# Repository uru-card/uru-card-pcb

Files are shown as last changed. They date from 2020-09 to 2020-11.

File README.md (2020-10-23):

# URU Card PCB

[URU Card](https://github.com/uru-card/uru-card) is an Arduino based FIDO2 Authenticator. This repository contains Eagle CAD design files to build the device.

## Schematic

The schematic for the URU Card is presented on the figure below:

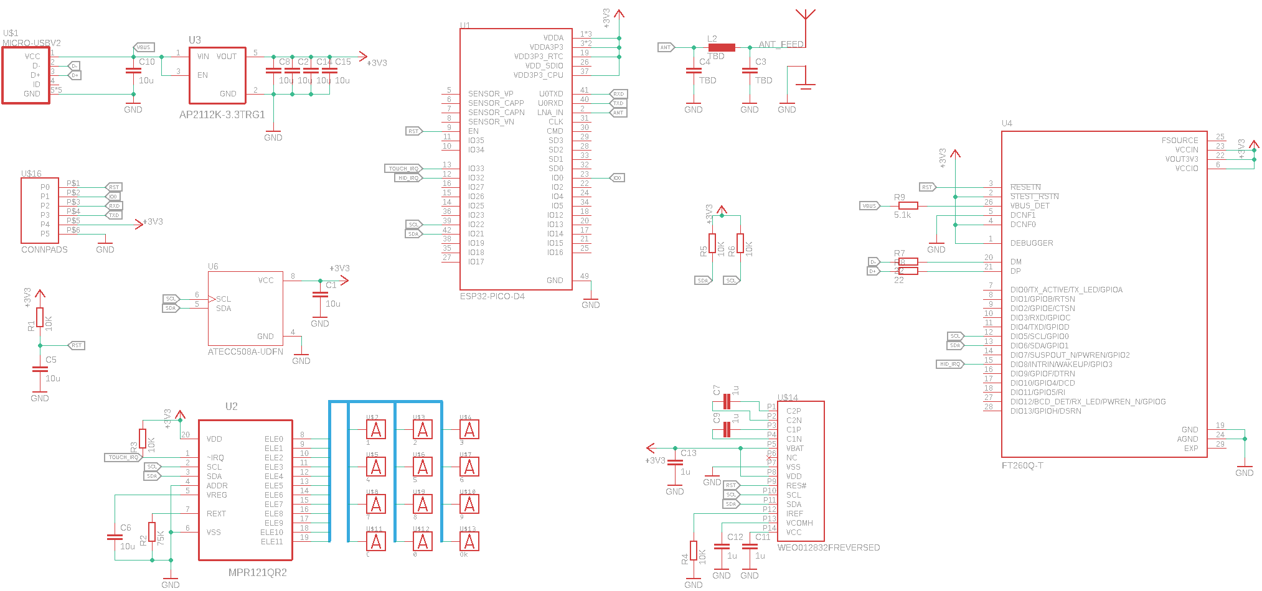
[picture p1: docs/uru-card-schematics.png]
URU Card schematic


Components requried to build the device

* ESP32 Pico D4 microcontroller
* ATECC508A or ATECC608A
* MPR121 touch keyboard controller
* SSD1306 based OLED display
* AP2112 voltage regulator
* MicroUSB socket
* A bunch of 0603 resistors and capacitors

## Mainboard PCB

The components are mounted on the mainboard. In fact it's the only PCB required to build the device.

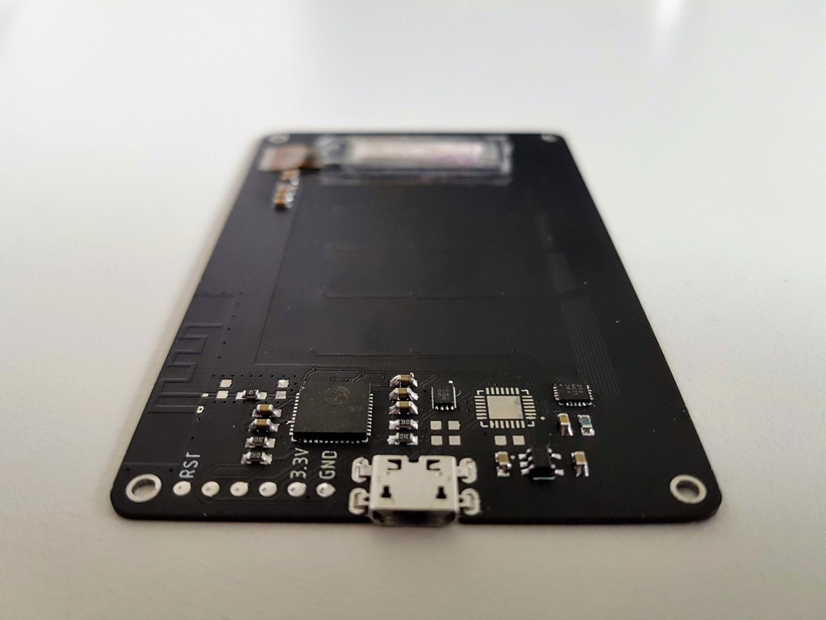
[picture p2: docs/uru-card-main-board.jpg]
URU Card mainboard


## Authors

* [**Andrey Ovcharov**](https://github.com/snakeye) - project owner

See also the list of [contributors](https://github.com/uru-card/uru-card/contributors) who participated in this project.

## References

* [Information about URU Card project](https://en.ovcharov.me/category/fido2/)

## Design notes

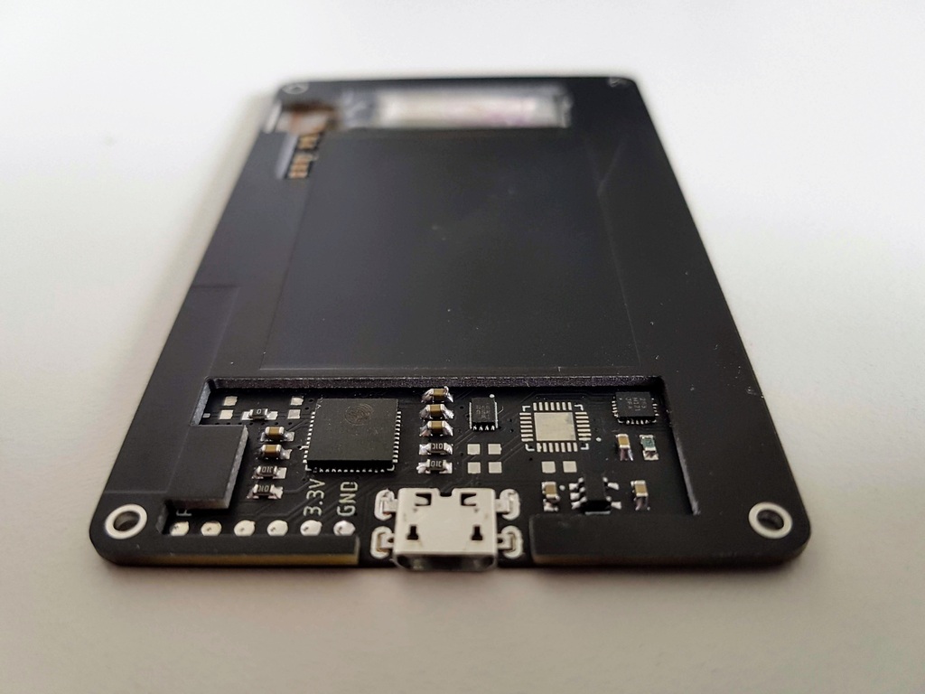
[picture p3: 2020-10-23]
docs/uru-card-spacer-board.jpg

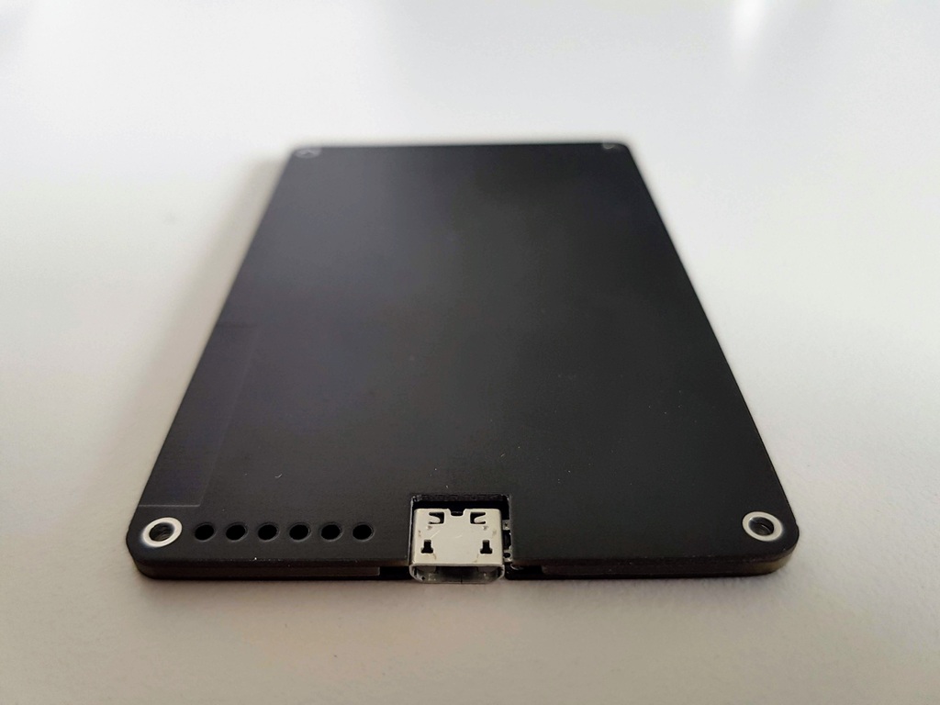
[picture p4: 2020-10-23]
docs/uru-card-cover-board.jpg

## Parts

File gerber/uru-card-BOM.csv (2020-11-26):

Comment | Designator | Footprint | LCSC Part # | Qty | Value | Device | Package | Parts | Description | AVAILABILITY | DESCRIPTION | MF | MP | PACKAGE | POPULARITY | PRICE | SPICEPREFIX
10K | R1, R3, R4, R5, R6 | R0603 | C25804 | 5 |  | R-EU_R0603 |  |  | RESISTOR, European symbol |  |  |  |  |  | 70 |  | R
10u | C1, C2, C5, C6, C8, C10, C14, C15 | C0603 | C19702 | 8 |  | C-EUC0603 |  |  | CAPACITOR, European symbol |  |  |  |  |  | 73 |  | C
1u | C7, C9, C11, C12, C13 | C0603 | C15849 | 5 |  | C-EUC0603 |  |  | CAPACITOR, European symbol |  |  |  |  |  | 73 |  | C
75K | R2 | R0603 | C23242 | 1 |  | R-EU_R0603 |  |  | RESISTOR, European symbol |  |  |  |  |  | 70 |  | R
AP2112K-3.3TRG1 | U3 | SOT95P285X140-5N | C51118 | 1 |  | AP2112K-3.3TRG1 |  |  | AP2112 Series 0.6 A 3.3 V Fixed Output SMT LDO Linear Regulator - SOT23-5 | Unavailable | AP2112 Series 0.6 A 3.3 V Fixed Output SMT LDO Linear Regulator - SOT23-5 | Diodes Inc. | AP2112K-3.3TRG1 | SOT-753 Diodes Inc. |  | None
ATECC508A-UDFN | U6 | SON50P200X300X60-9N | C145574 | 1 |  | ATECC508A-UDFN
ESP32-PICO-D4 | U1 | PQFN50P700X700X104-49N | C193707 | 1 |  | ESP32-PICO-D4 |  |  | The ESP32-PICO-D4 is a System-in-Package (SIP) module that is based on ESP32, providing complete Wi-Fi | Unavailable | WIFi/Bluetooth SIP | Espressif Systems | ESP32-PICO-D4 | SMD-48 Espressif Systems |  | None
MICRO-USBV2 | J1 | MICRO-USB-2 | C40958 | 1 |  | MICRO-USBV2 |  |  | Micro USB B connector
MPR121QR2 | U2 | QFN40P300X300X60-20N | C91322 | 1 |  | MPR121QR2 |  |  | Proximity Capacitive Touch Sensor Controller | Unavailable | Capacitive Touch Buttons, Slider, Wheel 20-QFN _3x3_ | NXP USA | MPR121QR2 | QFN-20 Resurgent |  | None
TBD | L2 | L2012C | C21189 | 1 |  | L-EUL2012C |  |  | INDUCTOR, European symbol |  |  |  |  |  | 2 |  | L

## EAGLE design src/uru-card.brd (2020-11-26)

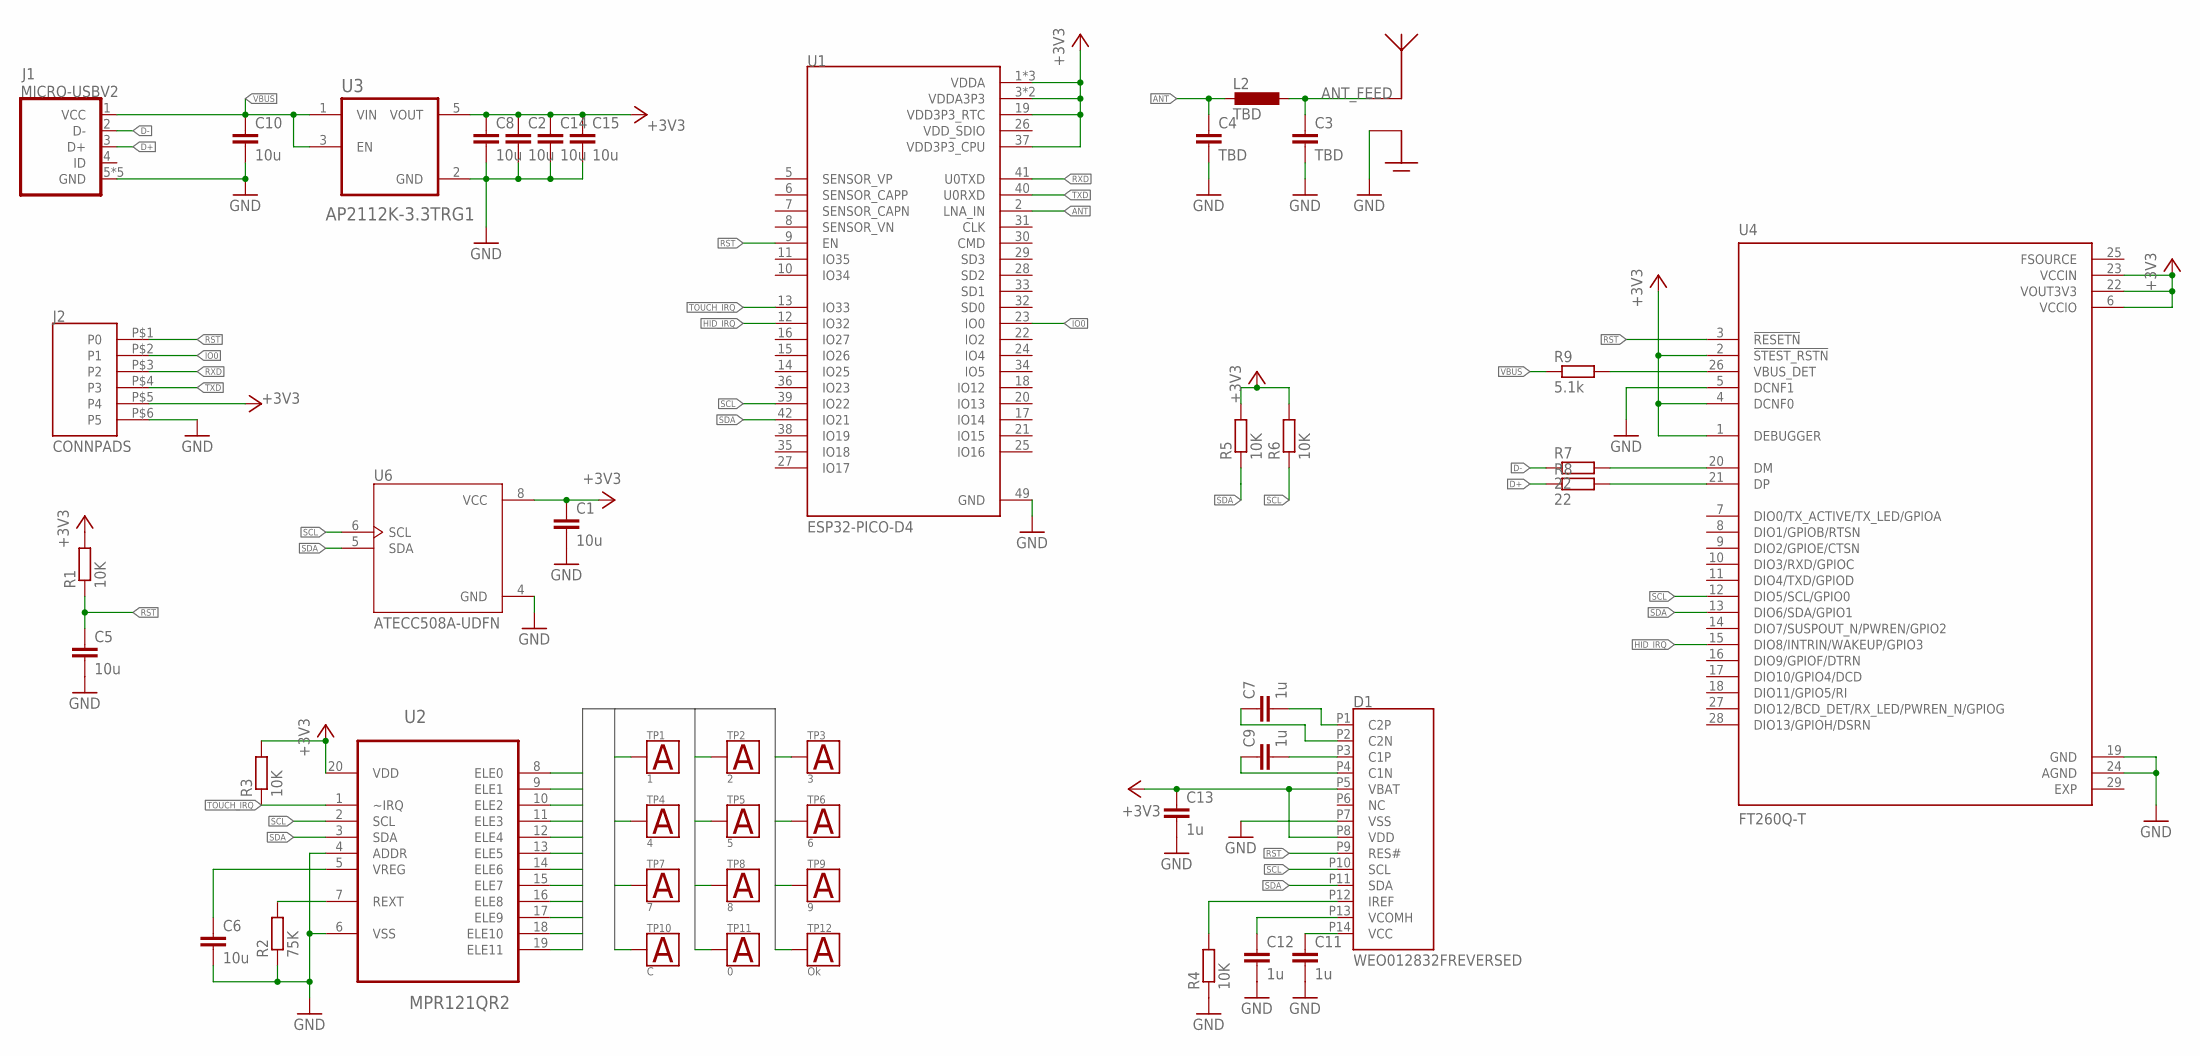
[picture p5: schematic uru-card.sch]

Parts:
C1, C2, C5, C6, C8, C10, C14, C15: 10u; C0603
C3, C4: TBD; C0603
C7, C9, C11, C12, C13: 1u; C0603
D1: WEO012832FREVERSED; WEO012832F-REVERSE
J1: MICRO-USBV2; MICRO-USB-2
J2: CONNPADS; PADS
L2: TBD; L2012C
R1, R3, R4, R5, R6: 10K; R0603
R2: 75K; R0603
R7, R8: 22; R0603
R9: 5.1k; R0603
TP1: 1; TOUCH
TP2: 2; TOUCH
TP3: 3; TOUCH
TP4: 4; TOUCH
TP5: 5; TOUCH
TP6: 6; TOUCH
TP7: 7; TOUCH
TP8: 8; TOUCH
TP9: 9; TOUCH
TP10: C; TOUCH
TP11: 0; TOUCH
TP12: Ok; TOUCH
U1: ESP32-PICO-D4; PQFN50P700X700X104-49N
U2: MPR121QR2; QFN40P300X300X60-20N
U3: AP2112K-3.3TRG1; SOT95P285X140-5N
U4: FT260Q-T; QFN50P500X500X80-29N
U6: ATECC508A-UDFN; SON50P200X300X60-9N
U$15: ANT-2_4_PCB; ANT-2_4

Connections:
0: TP11.P$1, U2.18 (ELE10)
1: TP1.P$1, U2.8 (ELE0)
2: TP2.P$1, U2.9 (ELE1)
3: TP3.P$1, U2.10 (ELE2)
4: TP4.P$1, U2.11 (ELE3)
5: TP5.P$1, U2.12 (ELE4)
6: TP6.P$1, U2.13 (ELE5)
7: TP7.P$1, U2.14 (ELE6)
8: TP8.P$1, U2.15 (ELE7)
9: TP9.P$1, U2.16 (ELE8)
+3V3: C1.1, C2.1, C8.1, C13.1, C14.1, C15.1, D1.P5 (VBAT), D1.P8 (VDD), J2.P$5 (P4), R1.2, R3.2, R5.2, R6.2, U1.1 (VDDA), U1.3 (VDDA3P3), U1.4 (VDDA3P3), U1.19 (VDD3P3_RTC), U1.37 (VDD3P3_CPU), U1.43 (VDDA), U1.46 (VDDA), U2.20 (VDD), U3.5 (VOUT), U4.1 (DEBUGGER), U4.2 (!STEST_RSTN), U4.4 (DCNF0), U4.6 (VCCIO), U4.22 (VOUT3V3), U4.23 (VCCIN), U6.8 (VCC)
ANT: C4.1, L2.2, U1.2 (LNA_IN)
ANT_FEED: C3.1, L2.1, U$15.FEED
C: TP10.P$1, U2.17 (ELE9)
D+: J1.3 (D+), R8.1
D-: J1.2 (D-), R7.1
EXP: U4.29 (EXP)
FSOURCE: U4.25 (FSOURCE)
GND: C1.2, C2.2, C3.2, C4.2, C5.2, C6.2, C8.2, C10.2, C11.2, C12.2, C13.2, C14.2, C15.2, D1.P7 (VSS), J1.5 (GND), J1.P$1 (GND), J1.P$2 (GND), J1.P$3 (GND), J1.P$4 (GND), J2.P$6 (P5), R2.1, R4.1, U1.49 (GND), U2.4 (ADDR), U2.6 (VSS), U3.2 (GND), U4.5 (DCNF1), U4.19 (GND), U4.24 (AGND), U6.4 (GND), U$15.GND
HID_IRQ: U1.12 (IO32), U4.15 (DIO8/INTRIN/WAKEUP/GPIO3)
IO0: J2.P$2 (P1), U1.23 (IO0)
unnamed: C9.1, D1.P4 (C1N)
unnamed: C9.2, D1.P3 (C1P)
unnamed: C7.1, D1.P2 (C2N)
unnamed: C7.2, D1.P1 (C2P)
unnamed: R7.2, U4.20 (DM)
unnamed: D1.P12 (IREF), R4.2
unnamed: C12.1, D1.P13 (VCOMH)
unnamed: C11.1, D1.P14 (VCC)
unnamed: R8.2, U4.21 (DP)
unnamed: R9.2, U4.26 (VBUS_DET)
unnamed: R2.2, U2.7 (REXT)
unnamed: C6.1, U2.5 (VREG)
OK: TP12.P$1, U2.19 (ELE11)
RST: C5.1, D1.P9 (RES#), J2.P$1 (P0), R1.1, U1.9 (EN), U4.3 (!RESETN)
RXD: J2.P$3 (P2), U1.41 (U0TXD)
SCL: D1.P10 (SCL), R6.1, U1.39 (IO22), U2.2 (SCL), U4.12 (DIO5/SCL/GPIO0), U6.6 (SCL)
SDA: D1.P11 (SDA), R5.1, U1.42 (IO21), U2.3 (SDA), U4.13 (DIO6/SDA/GPIO1), U6.5 (SDA)
TOUCH_IRQ: R3.1, U1.13 (IO33), U2.1 (~IRQ)
TXD: J2.P$4 (P3), U1.40 (U0RXD)
VBUS: C10.1, J1.1 (VCC), R9.1, U3.1 (VIN), U3.3 (EN)
VDD_SDIO: U1.26 (VDD_SDIO)

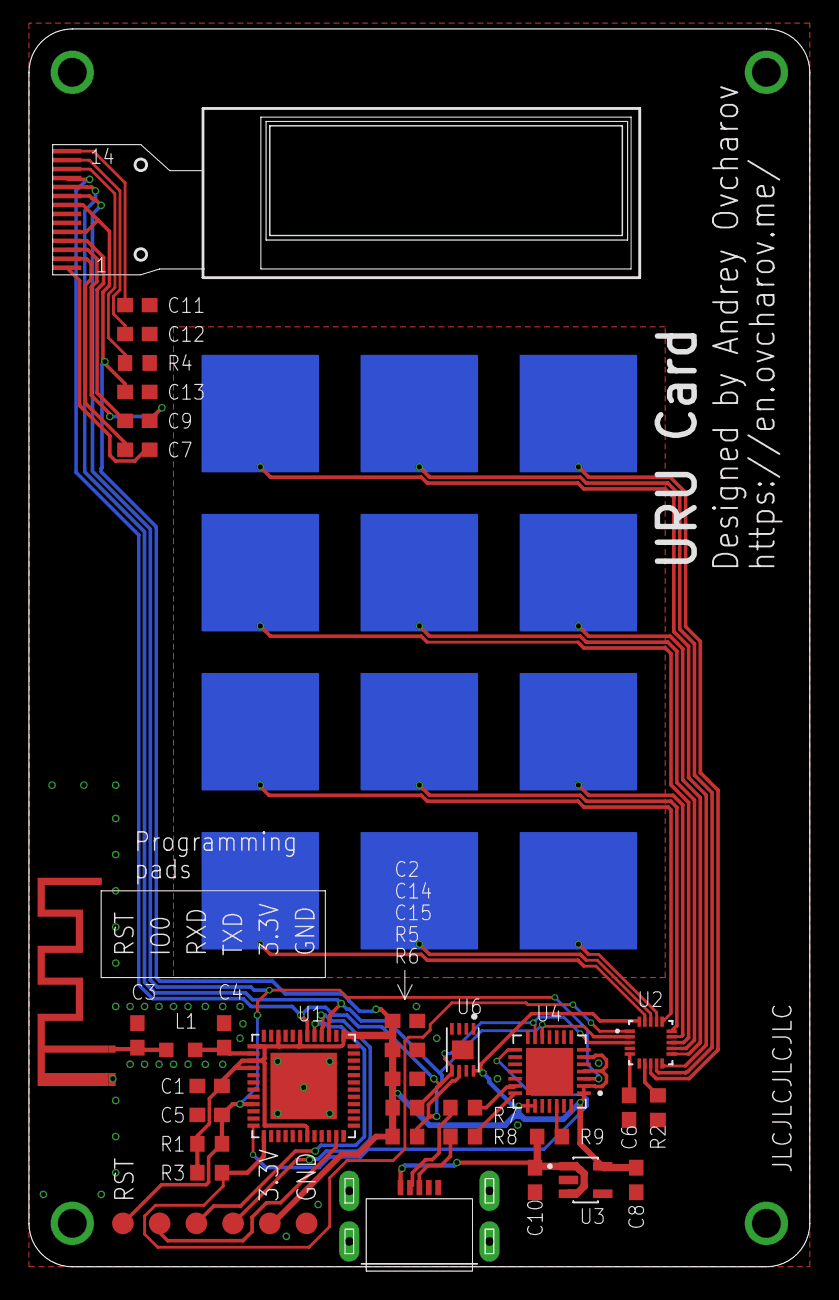
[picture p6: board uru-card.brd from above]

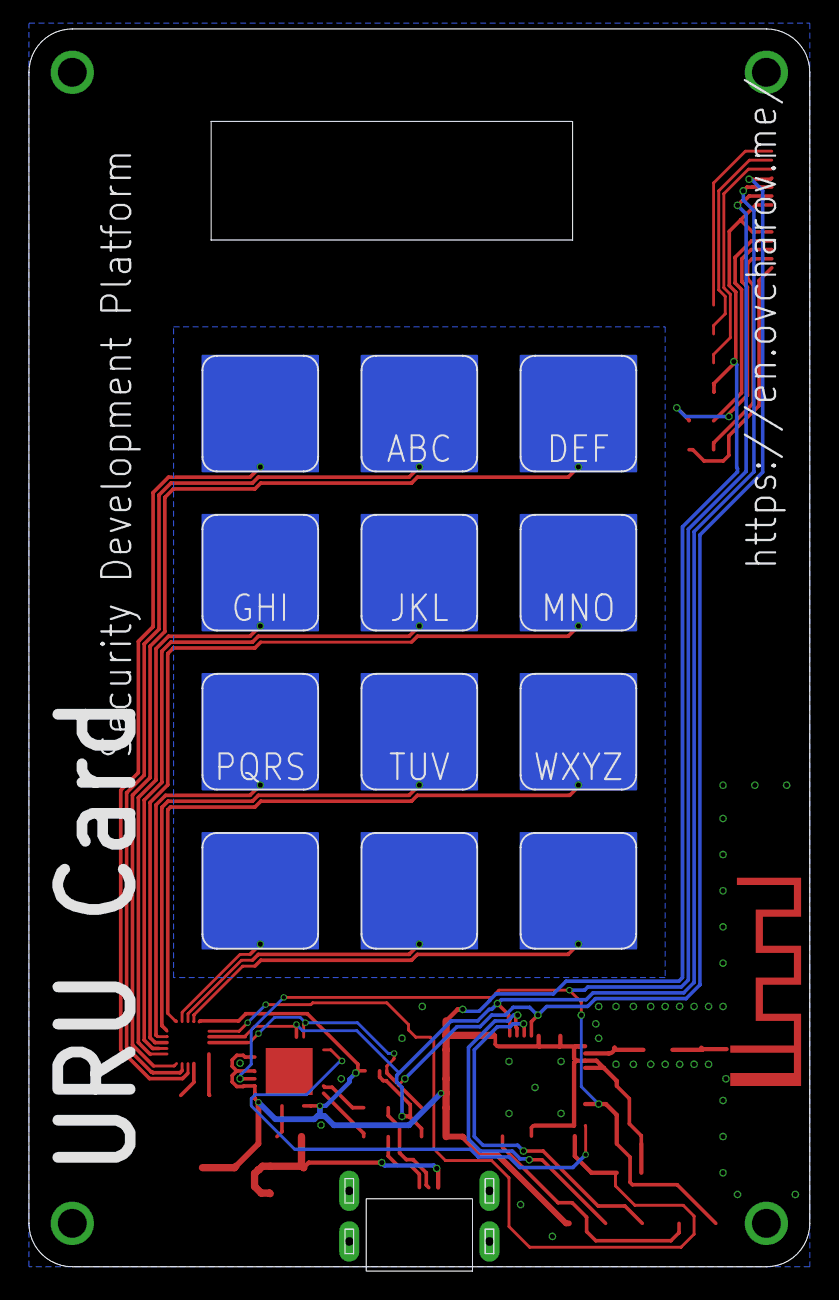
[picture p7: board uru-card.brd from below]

Board: 2 copper layers, 54.0 x 85.6 mm, 46 parts (12 on the bottom side), 39 nets.

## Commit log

2020-04-16 Added FT260Q USB I2C
    [uru-card.brd, uru-card.sch]
2020-04-16 Routed USB HID
    [uru-card.brd, uru-card.sch]
2020-04-16 Changed routing for the display component
    [uru-card.brd, uru-card.sch]
2020-08-31 Design refactoring
    Replaced the antenna with PCB one
    Moved connector
    Replaced tantalum capacitor with ceramic ones
    [uru-card.brd, uru-card.sch]
2020-09-02 fixed the trace crossing cut out
    [uru-card.brd]
2020-09-27 Fixed incorrect connections
    [uru-card.brd, uru-card.sch]
2020-09-27 Added boards for covering
    [uru-card-cover.brd, uru-card-cover.sch, uru-card-inner.brd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]
2020-09-27 Removed wire stub
    [uru-card.brd]
2020-09-28 Release 1.2
    [uru-card-cover.brd, uru-card.brd]
2020-11-10 tiny connector board
    [connector.brd, connector.sch]
2020-11-12 Updated CAM job
    [uru-card.brd, uru-card.sch]
2020-11-14 Added part names on the board
    [uru-card.brd]
2020-11-26 JLCPCB production files
    [uru-card-BOM.csv, uru-card.brd, uru-card.csv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]
2020-12-03 Improved layout of connector board
    [connector.brd]
